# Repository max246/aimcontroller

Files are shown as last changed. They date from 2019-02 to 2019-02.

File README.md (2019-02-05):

# Playstation Aim Controller 

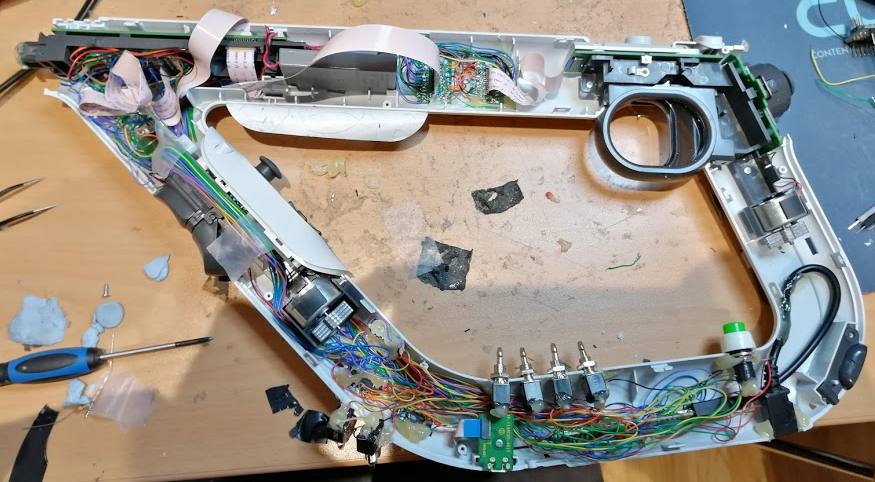
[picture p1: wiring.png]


Hack of the Playstation aim controller

I have re-wired the controller into a Teensy 3.6 to "filter the commands" and potentially create a combination to help or cheat in games. 
The idea was to understand how it would be possible to do it and there was no intetion to allow easy cheat in games.

Using 3 digital potentiometer allowed me to even read the analog inputs and reprodue them from the micro controller.

There were extra 6 buttons to activate other feature that could be implemented.

The source code provide only the functionality of COPY but a Burst or other combination can be developed.

The power supply was connected directly to the main battery and the controller would have a main switch to deactivate it, unfortunatly the MCP will not keep the last output, therefore I suggest to turn off the remote first then the Teensy.

The re-wiring took a lot of time and I suggest to get a very good pair of tweezer to pull them around the controller, blue tac is very handy to stick them down while working on the right length of wires!

## PCB

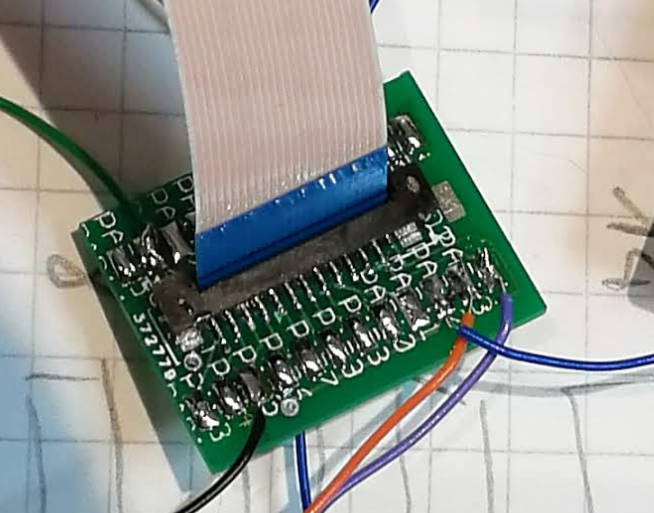
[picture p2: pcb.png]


Connector to solder on the PCB is a TE Connectivity FPC 0.5mm Pitch 24 Way Straight SMT Female FPC Connector. 
Part number: 2-1734742-4

RS components https://uk.rs-online.com/web/p/fpc-connectors/9097441

The ribbon cable is a 24 Pins AWM 2896 VW-1 30V 80C, which you can source on aliexpress or by buying  a broken or cheap second aim controller ( the path I followed ).

## Reverse Engineering

I have worked out each pins what they do, but please double check the orientation before connecting everything, it will be easy as the ground pins are close by and checking from the bespoke PCB to the actually Playstation board will take few seconds.

I have made a small PDF with the schematic of what I found out ( [LINK](https://raw.githubusercontent.com/max246/aimcontroller/master/PS4%20Aim%20Controller.pdf)
 ) .

R2 an L2 are not clever re-created, just a hack I found that worked, they apparently have a "pull up" resistor of X ohm and the pressure change the voltage difference. 
I have used a digital potentiometer to short the Spare R2/L2 to the R2/L2 to create the similar beahvour. It worked!

Joystick Front ( Left ) and Joystick Back ( Right ) were easy to work it out, and wired up with a digital potentiometer.

The chip I have used is MCP4251-104E/P 100k Ohm from RS ( https://uk.rs-online.com/web/p/digital-potentiometers/7239731/ )

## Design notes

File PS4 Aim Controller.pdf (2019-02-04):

# Playstation Aim Controller

# Reverse engineering

# Main board to PCB

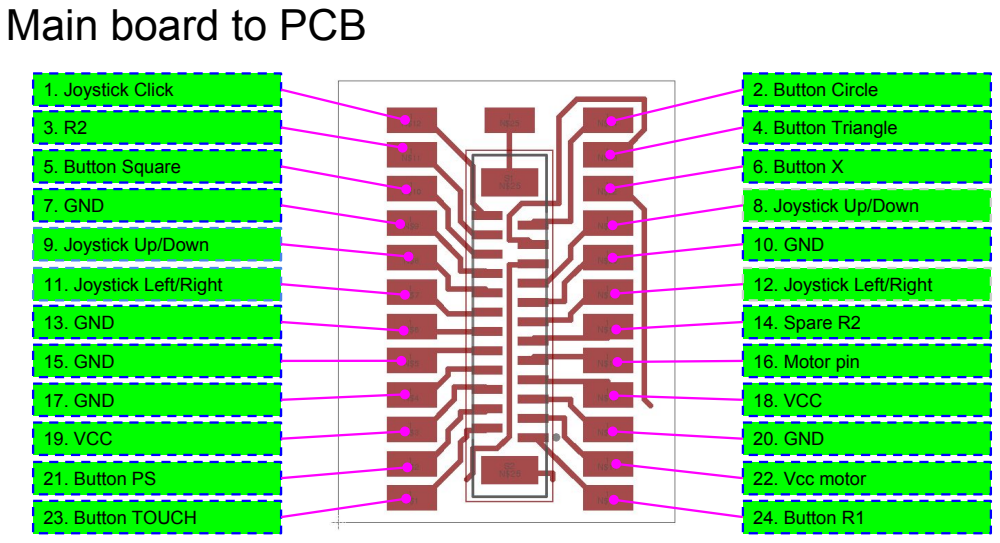
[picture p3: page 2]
1. Joystick Click; 5. Button Square; 7. GND; 13. GND; 15. GND; 17. GND; 19. VCC; 21. Button PS; 23. Button TOUCH; 2. Button Circle; 4. Button Triangle; 6. Button X; 10. GND; 14. Spare R2; 16. Motor pin; 18. VCC; 20. GND; 22. Vcc motor; 24. Button R1

8. Joystick Up/Down

9. Joystick Up/Down

11. Joystick Left/Right

12. Joystick Left/Right

# PCB to Trigger Controller (Back)

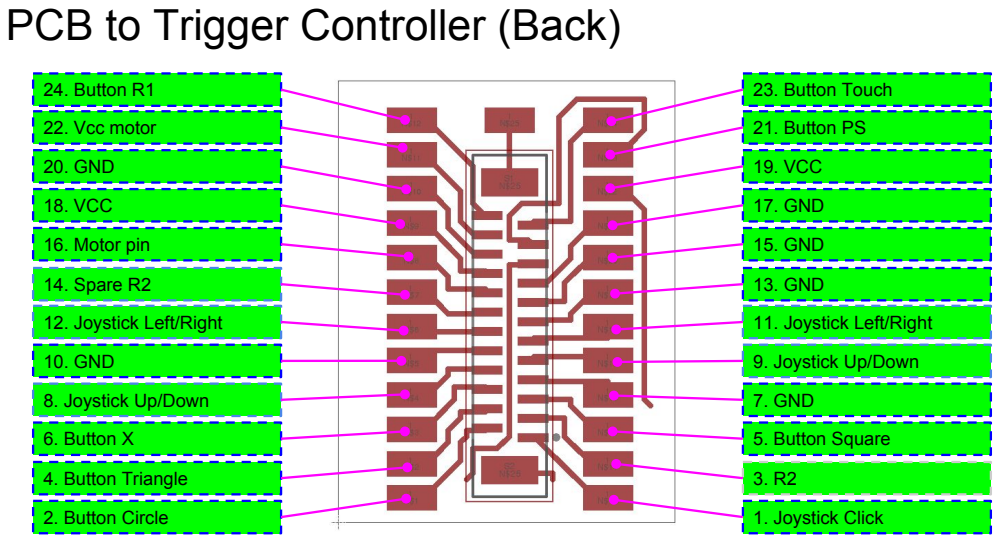
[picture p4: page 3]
24. Button R1; 22. Vcc motor; 20. GND; 18. VCC; 16. Motor pin; 14. Spare R2; 10. GND; 6. Button X; 4. Button Triangle; 2. Button Circle; 23. Button Touch; 21. Button PS; 19. VCC; 17. GND; 15. GND; 13. GND; 7. GND; 5. Button Square; 1. Joystick Click

12. Joystick Left/Right

11. Joystick Left/Right

9. Joystick Up/Down

8. Joystick Up/Down

# PCB to Front Controller

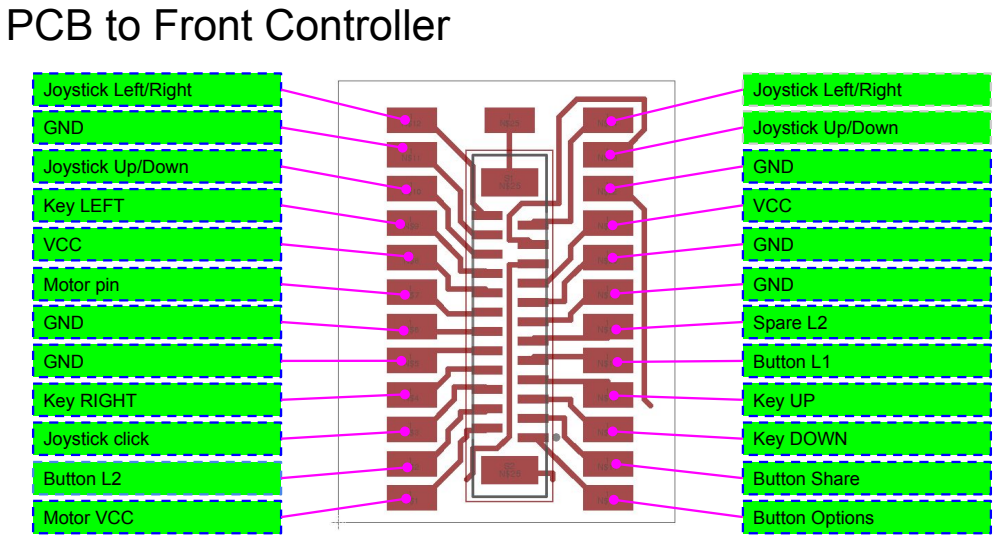
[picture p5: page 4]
GND; Key LEFT; VCC; Motor pin; Key RIGHT; Joystick click; Button L2; Motor VCC; Spare L2; Button L1; Key UP; Key DOWN; Button Share; Button Options

Joystick Left/Right

Joystick Up/Down

# Main board to PCB

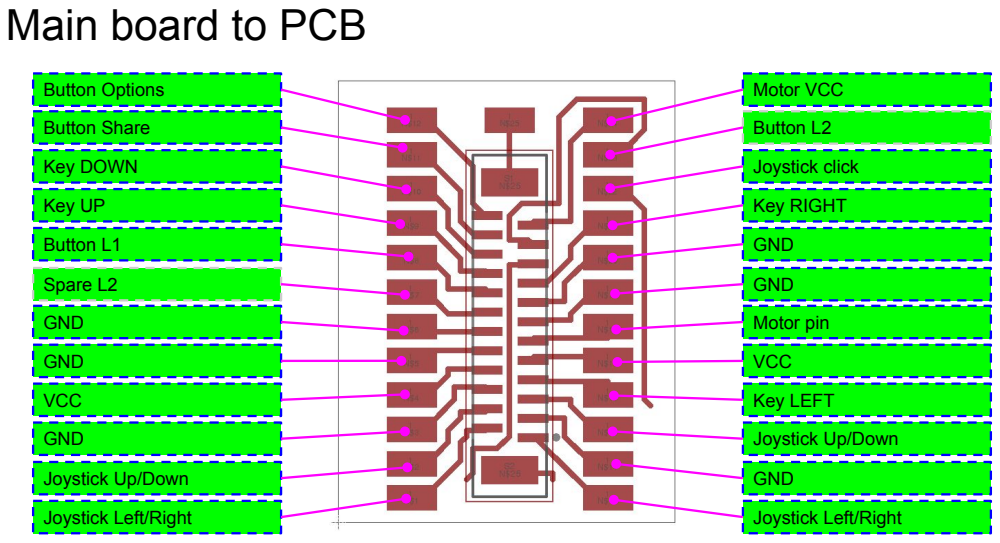
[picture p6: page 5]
Button Options; Button Share; Key DOWN; Key UP; Button L1; Spare L2; GND; VCC; Motor VCC; Button L2; Joystick click; Key RIGHT; Motor pin; Key LEFT

Joystick Up/Down

Joystick Left/Right

# Teensy 3.6 pin outs

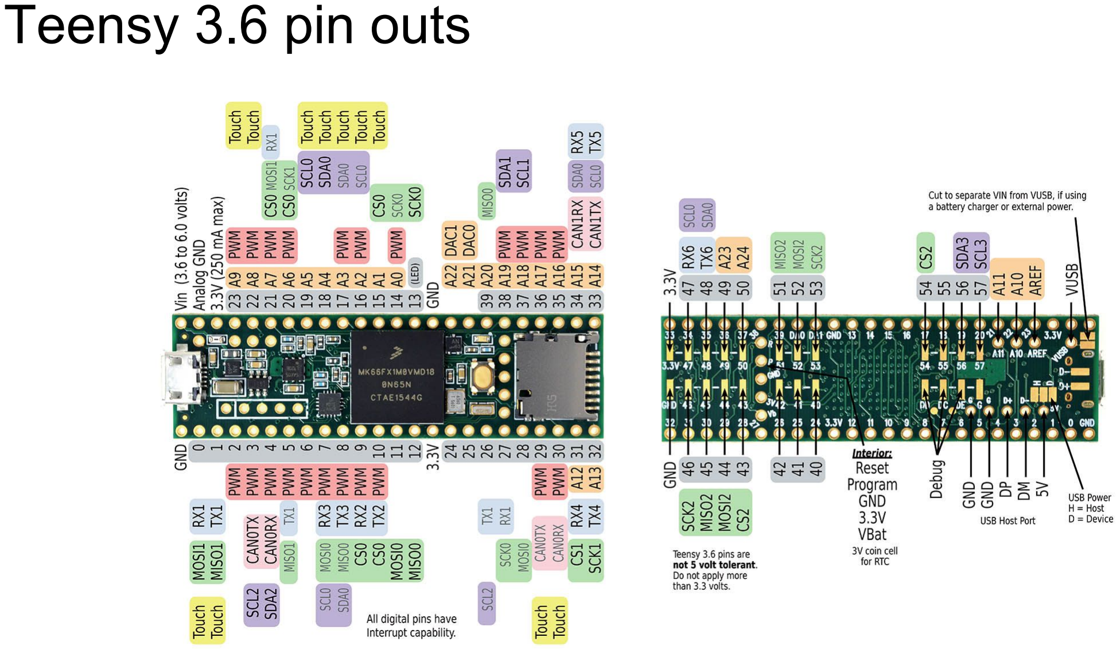
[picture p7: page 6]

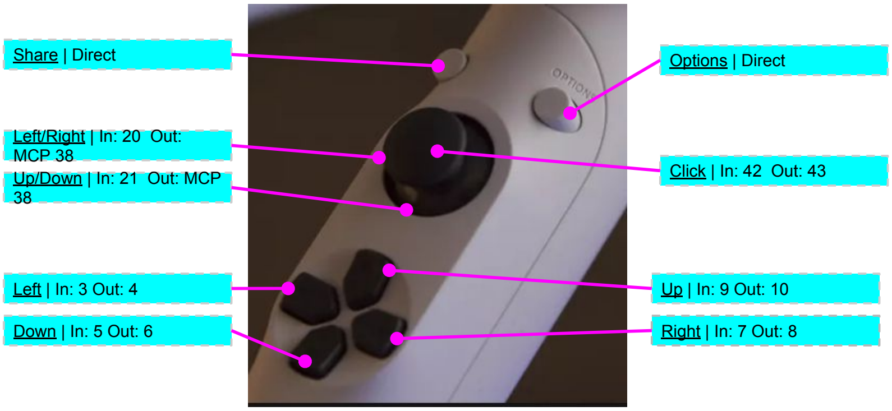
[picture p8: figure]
Share | Direct; Left/Right | In: 20 Out: MCP 38 Up/Down | In: 21 Out: MCP 38; Click | In: 42 Out: 43; Options | Direct; Left | In: 3 Out: 4; Down | In: 5 Out: 6; Up | In: 9 Out: 10; Right | In: 7 Out: 8

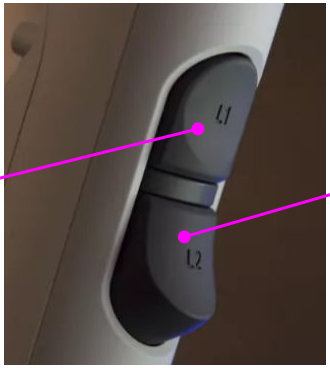
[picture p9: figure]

L1 | In: 40 Out: 41 | L2 | In: 39 Out: MCP 36

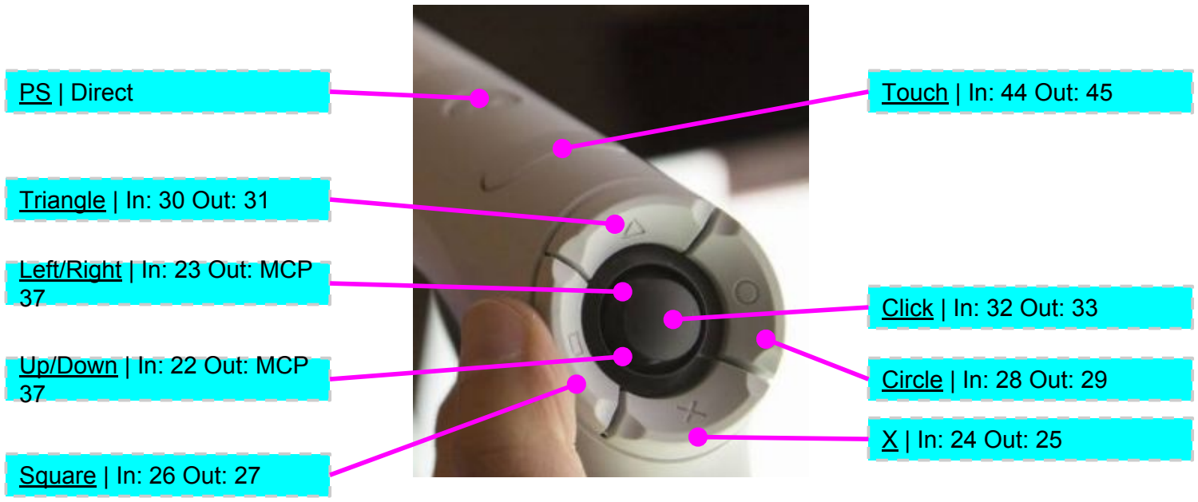
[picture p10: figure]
Square | In: 26 Out: 27; Up/Down | In: 22 Out: MCP; Circle | In: 28 Out: 29; X | In: 24 Out: 25; Click | In: 32 Out: 33; Left/Right | In: 23 Out: MCP 37; Triangle | In: 30 Out: 31; PS | Direct; Touch | In: 44 Out: 45

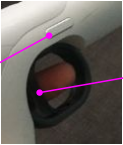
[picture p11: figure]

R1 | In: 34 Out: 35 | R2 | In 14 Out: MCP 36

# Digital potentiometer for R2 and L2

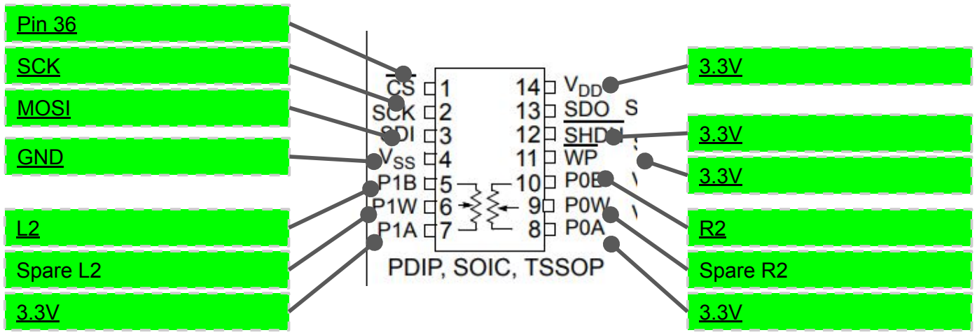
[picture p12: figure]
Pin 36; SCK; GND; MOSI; Spare R2; Spare L2

# Digital potentiometer for Back Joystick

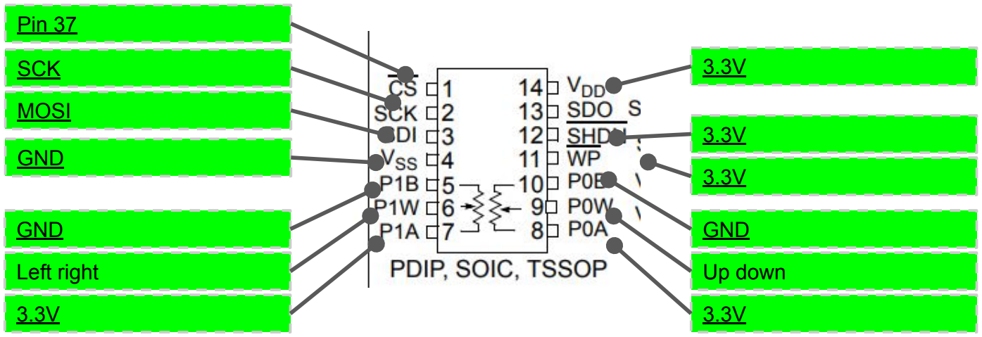
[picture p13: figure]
Pin 37; SCK; GND; MOSI; Up down; Left right

# Digital potentiometer for Front Joystick

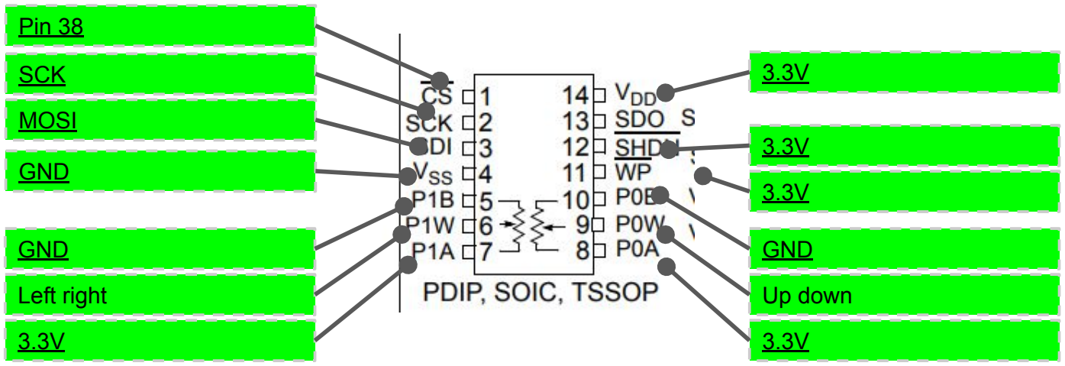
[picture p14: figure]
Pin 38; SCK; GND; MOSI; Up down; Left right

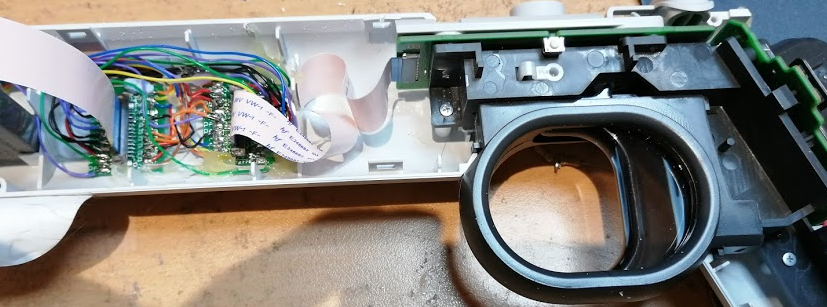
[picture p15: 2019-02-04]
top section 2.png

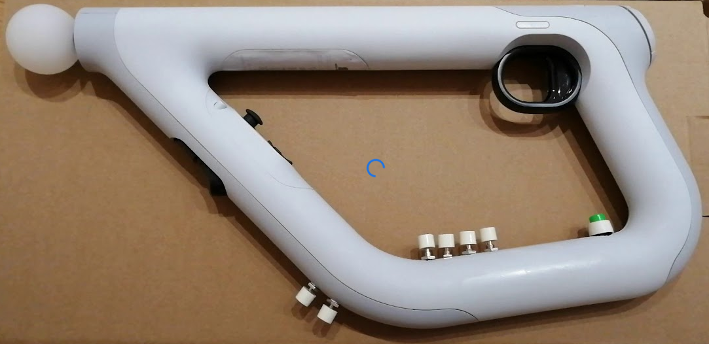
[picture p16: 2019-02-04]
controller.png

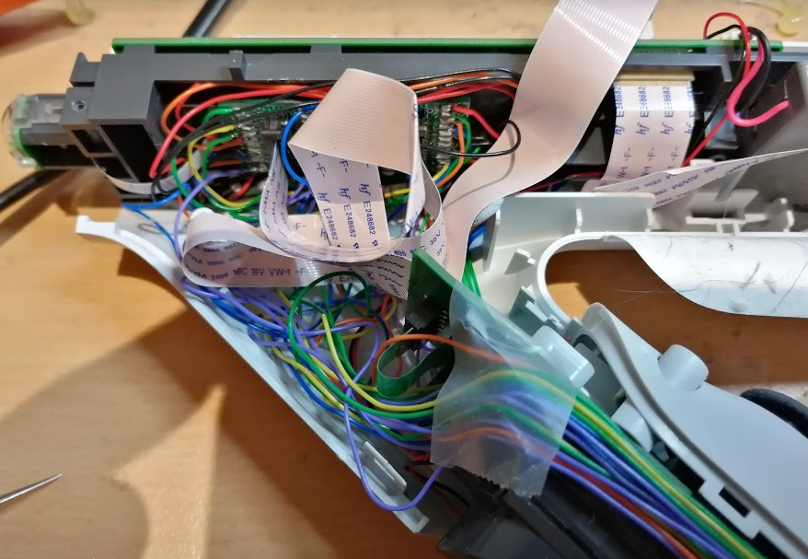
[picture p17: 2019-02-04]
front section.png

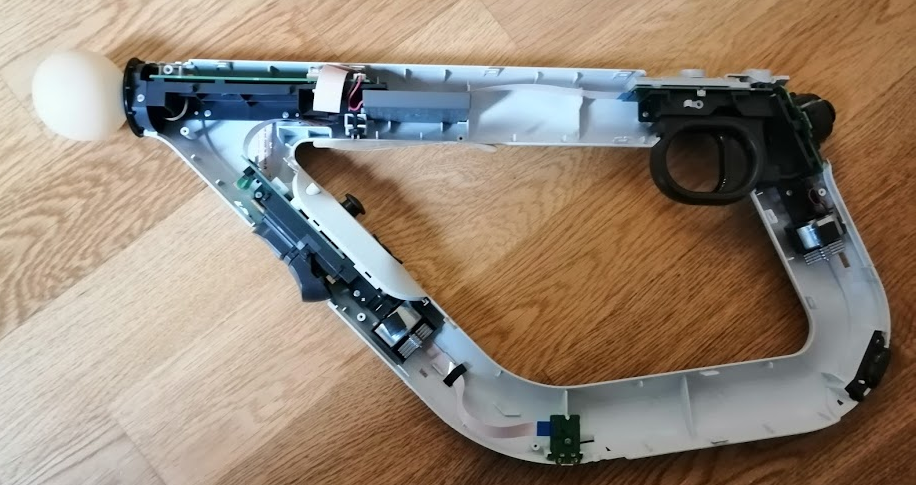
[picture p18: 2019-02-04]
original.png

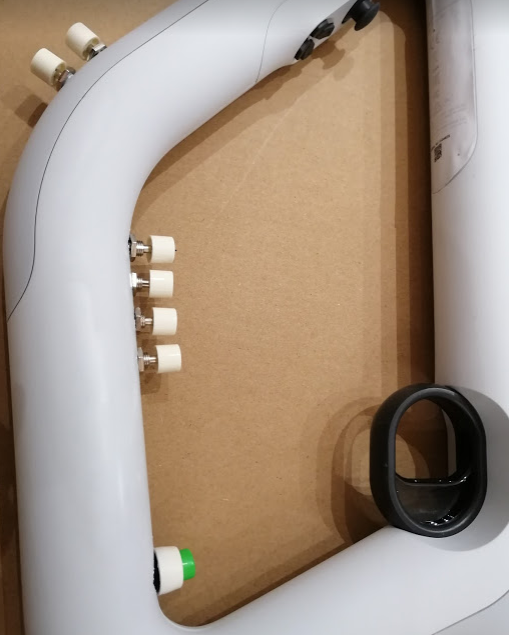
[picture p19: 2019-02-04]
buttons.png

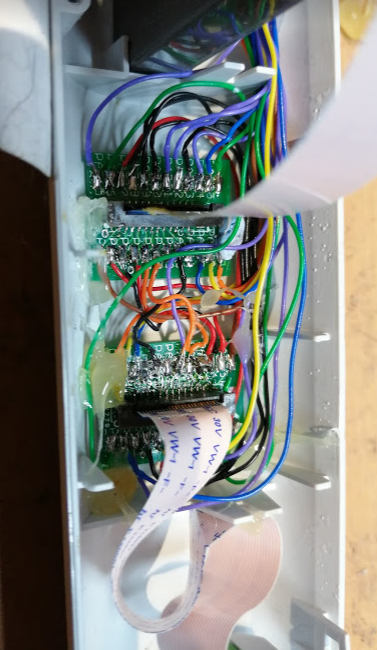
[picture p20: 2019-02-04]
top section.png

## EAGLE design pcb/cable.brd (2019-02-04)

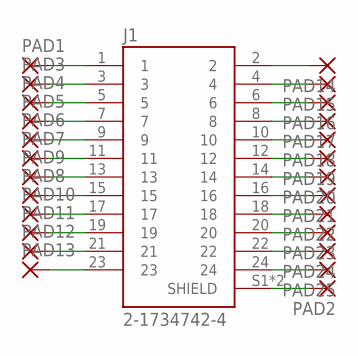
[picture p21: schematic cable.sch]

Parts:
J1: 2-1734742-4; TE_2-1734742-4
PAD1, PAD2, PAD3, PAD4, PAD5, PAD6, PAD7, PAD8, PAD9, PAD10, PAD11, PAD12, PAD13, PAD14, PAD15, PAD16, PAD17, PAD18, PAD19, PAD20, PAD21, PAD22, PAD23, PAD24, PAD25: SMD2; SMD1,27-2,54

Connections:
unnamed: J1.2, PAD14.1
unnamed: J1.4, PAD15.1
unnamed: J1.6, PAD16.1
unnamed: J1.8, PAD17.1
unnamed: J1.10, PAD18.1
unnamed: J1.12, PAD19.1
unnamed: J1.14, PAD20.1
unnamed: J1.16, PAD21.1
unnamed: J1.18, PAD22.1
unnamed: J1.20, PAD23.1
unnamed: J1.22, PAD24.1
unnamed: J1.24, PAD25.1
unnamed: J1.1, PAD1.1
unnamed: J1.3, PAD3.1
unnamed: J1.5, PAD4.1
unnamed: J1.7, PAD5.1
unnamed: J1.9, PAD6.1
unnamed: J1.11, PAD7.1
unnamed: J1.13, PAD9.1
unnamed: J1.15, PAD8.1
unnamed: J1.17, PAD10.1
unnamed: J1.19, PAD11.1
unnamed: J1.21, PAD12.1
unnamed: J1.23, PAD13.1
unnamed: J1.S1 (SHIELD), J1.S2 (SHIELD), PAD2.1

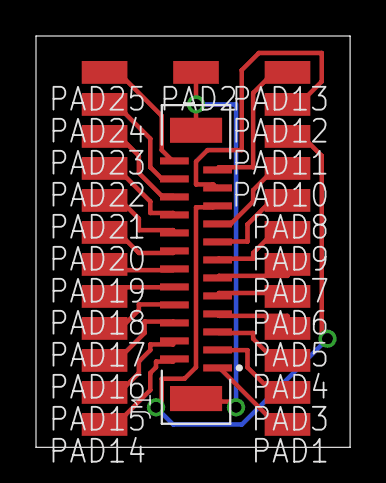
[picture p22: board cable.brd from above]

Board: 2 copper layers, 17.4 x 22.9 mm, 26 parts (0 on the bottom side), 25 nets.

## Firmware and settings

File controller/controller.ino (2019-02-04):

#include <SPI.h>


int btn_r1_in = 34;
int btn_r1_out = 35;
int btn_touch_in = 44;
int btn_touch_out = 45;
int btn_x_in = 24;
int btn_x_out = 25;
int btn_c_in = 28;
int btn_c_out = 29;
int btn_s_in = 26;
int btn_s_out = 27;
int btn_t_in = 30;
int btn_t_out = 31;
int btn_left_in = 3;
int btn_left_out = 4;
int btn_right_in = 7;
int btn_right_out = 8;
int btn_up_in = 9;
int btn_up_out = 10;
int btn_down_in = 5;
int btn_down_out = 6;
int btn_stick1_in = 32;
int btn_stick1_out = 33;
int btn_stick2_in = 42;
int btn_stick2_out = 43;
int btn_l1_in = 40;
int btn_l1_out = 41;

int btn_l2_in = 39;
int btn_r2_in = 14;

int pot_l2_r2 = 36;
int pot_joystick_back = 37;
int pot_joystick_front = 38;
int pot_joystick_back_horizontal = 23;
int pot_joystick_back_vertical = 22;
int pot_joystick_front_horizontal = 21;
int pot_joystick_front_vertical = 20;

int btn_extra_1 = 52; //47;
int btn_extra_2 = 51; //48;
int btn_extra_3 = 50; //49;
int btn_extra_4 = 49; //50;
int btn_extra_5 = 48; //51;
int btn_extra_6 = 47; //52; 

#define FUNCTION_COPY 0

#define STATUS_IDLE 0
#define STATUS_ON 1

struct button  {
  int pin_in;
  int pin_out;
  int type_function;
  int min_time_hold;
  int burst_delay;
  unsigned last_pressed;
  int status;
} ;

button buttons[13];

button extra_buttons[7];



void setup() {
  // Serial.begin(9600);

  //** SETUP BUTTONS **/
  //L1 button
  buttons[0] = {btn_l1_in, btn_l1_out, FUNCTION_COPY, 0, 0};

  //R1 button
 buttons[1] = {btn_r1_in, btn_r1_out, FUNCTION_COPY, 0, 0};

  //Touch pad button
  buttons[2] = {btn_touch_in, btn_touch_out, FUNCTION_COPY, 0, 0};

  //X button
  buttons[3] = {btn_x_in, btn_x_out, FUNCTION_COPY, 0, 0};

  //Circle button
  buttons[4] = {btn_c_in, btn_c_out, FUNCTION_COPY, 0, 0};

  //Square button
  buttons[5] = {btn_s_in, btn_s_out, FUNCTION_COPY, 0, 0};

  //Triangle button
  buttons[6] = {btn_t_in, btn_t_out, FUNCTION_COPY, 0, 0};

  //Left button
  buttons[7] = {btn_left_in, btn_left_out, FUNCTION_COPY, 0, 0};

  //Right button
  buttons[8] = {btn_right_in, btn_right_out, FUNCTION_COPY, 0, 0};

  //Up button
  buttons[9] = {btn_up_in, btn_up_out, FUNCTION_COPY, 0, 0};

  //Down button
  buttons[10] = {btn_down_in, btn_down_out, FUNCTION_COPY, 0, 0};

  //Joystick stick 1 button
  buttons[11] = {btn_stick1_in, btn_stick1_out, FUNCTION_COPY, 0, 0};

  //Joystick stick 2 button
  buttons[12] = {btn_stick2_in, btn_stick2_out, FUNCTION_COPY, 0, 0};


  //EXTRA BUTTONS
  extra_buttons[0] = {btn_extra_1, 0, 0, 0, 0};
  extra_buttons[1] = {btn_extra_2, 0, 0, 0, 0};
  extra_buttons[2] = {btn_extra_3, 0, 0, 0, 0};
  extra_buttons[3] = {btn_extra_4, 0, 0, 0, 0};
  extra_buttons[4] = {btn_extra_5, 0, 0, 0, 0};
  extra_buttons[5] = {btn_extra_6, 0, 0, 0, 0};

  

  //** DEFINE MODE EACH INPUT
  for (int i = 0; i < 13; i++) {
    pinMode(buttons[i].pin_out, OUTPUT);
    if (i == 11 || i == 12 || i == 1 || i == 0) 
          pinMode(buttons[i].pin_in, INPUT_PULLDOWN);
    else     
    pinMode(buttons[i].pin_in, INPUT_PULLUP);
  }
    


  for (int i = 0; i < 6; i++) {   
    pinMode(extra_buttons[i].pin_in, INPUT_PULLUP);
     
  }

  //** SETUP SPI CONNECTION
  SPI.begin();
  pinMode(pot_joystick_back, OUTPUT);
  digitalWrite(pot_joystick_back, HIGH);
  pinMode(pot_joystick_front, OUTPUT);
  digitalWrite(pot_joystick_front, HIGH);
  pinMode(pot_l2_r2, OUTPUT);
  digitalWrite(pot_l2_r2, HIGH);

  pinMode(btn_r2_in, INPUT_PULLDOWN);
  pinMode(btn_l2_in, INPUT_PULLDOWN);

  //Set middle points for potentiometer
  write_pot(255, 0, 2);
  write_pot(255, 1, 2);
  
  write_pot(127, 0, 0);
  write_pot(127, 1, 0);
   
  write_pot(127, 0, 1);
  write_pot(127, 1, 1);
}

void loop() {
  readButtons();
  readPotentiometer();
  readExtraButtons();
}

void readExtraButtons() {

 boolean btn_status = false;
 for (int i = 0; i < 6; i++) {
    btn_status = digitalRead(extra_buttons[i].pin_in);

    if (btn_status == false) {
      if (extra_buttons[i].last_pressed == 0) {
        extra_buttons[i].last_pressed = millis();   
        extra_buttons[i].status = STATUS_ON;     
      }
    } else { 
      if (extra_buttons[i].status == STATUS_ON && (millis()-extra_buttons[i].last_pressed) > 50) { //Release button
            
          if (i == 0) { ///BUTTON 1
          }
          else if (i == 1) {
          }
          else if (i == 2) {
          }
          else if (i == 3) {
          }
          else if (i == 4) {
          }
          else if (i == 5) {
          }
      extra_buttons[i].last_pressed = 0;
      extra_buttons[i].status = STATUS_IDLE;
      
      }
    }  
 }
  
}

void readButtons() {
  boolean btn_status = false;
  for (int i = 0; i < 13; i++) {
    btn_status = digitalRead(buttons[i].pin_in);
    
    //Copy status as normal beahvour
    if (buttons[i].type_function == FUNCTION_COPY) 
      digitalWrite(buttons[i].pin_out, btn_status);
  }

 
}

void readPotentiometer() {  
   //** BACK JOYSTICK , DEFINE COPY OR ELSE 
   int pot1 = analogRead(pot_joystick_back_horizontal);
   int pot2 = analogRead(pot_joystick_back_vertical);

   if (true) { 
      //left and right
      int scale = map(pot1,0,1024, 0 ,256);
      write_pot(scale, 1, 0);
      //Up and down
      int scale2 = map(pot2,0,1024, 0 ,256);
      write_pot(scale2, 0, 0);
   } 

   //*** FRONT JOYSTICK, DEFINE COPY OR ELSE
   pot1 = analogRead(pot_joystick_front_horizontal);
   pot2 = analogRead(pot_joystick_front_vertical);

   if (true) { 
      //up and down
      int scale = map(pot1,0,1024, 0 ,256);     
      write_pot(scale, 0, 1);
      //left and right
      int scale2 = map(pot2,0,1024, 0 ,256);
      write_pot(scale2, 1, 1); 
   } 

   //*** R2 and L2 BUTTONS, define copy or else
   pot1 = analogRead(btn_l2_in);
   pot2 = analogRead(btn_r2_in);

   if (true) {
    //R2
    if (pot2 >= 700 && pot2 <=900) {
       int scale = map(pot2, 700, 900,100,0);
       write_pot(scale, 0, 2);
    }

    //L2
    if (pot1 >= 700 && pot1 <=950) {
          int scale2 = map(pot1, 700, 950,50,0);
          write_pot(scale2, 1, 2);
    }
   }
}

// Sets the potentiometer (channel 0 or 1) to a defined setting (0 to 256)

void write_pot(int setting, int channel, int type) {
  unsigned int cmd;

  cmd |= (channel << 12); // set the channel we're going to write to (memory address 0 and 1)
  cmd |= (setting & 0x1FF); // set the bottom 9 bits of the command
  byte cmdMSB = (byte)(cmd >> 8);
  byte cmdLSB = (byte)(cmd & 0xFF);

  if (type == 0)
    digitalWrite(pot_joystick_back, LOW);
   else  if (type == 1)
    digitalWrite(pot_joystick_front, LOW);
  else  if (type == 2)
    digitalWrite(pot_l2_r2, LOW);
    
  SPI.transfer(cmdMSB);
  SPI.transfer(cmdLSB);

  if (type == 0)
    digitalWrite(pot_joystick_back, HIGH);
  else if (type ==1)
    digitalWrite(pot_joystick_front, HIGH);
  else  if (type == 2)
    digitalWrite(pot_l2_r2, HIGH);
    
}
